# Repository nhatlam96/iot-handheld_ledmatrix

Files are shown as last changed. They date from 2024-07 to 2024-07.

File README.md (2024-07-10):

# Electronica Emporium

- N = Luong, Nhat-Lam
- P = Sandler, Paul
- NP = Both

## Individual and group work packages

- server:
  - N: .env (deleted secret), Dockerfile, mosquitto.conf, mqtt_tictactoe.py
  - P: mqtt_laby.py
- client:
  - N: .env (deleted secret), tictactoe.py
  - P: labyrinth.py, menu.py, common_functions.py
  - NP: mqtt_client.py, vibrator.py, gyroscope_handler.py

## Project timeline

- **Project planning**
  - [x] (NP) Architecture, Project plan, general and individual work packages, hardware research and orders
- **Project implementation**
  - Hardware
    - [x] Setup and testing
      - [x] (N) Connect Buttons and test
      - [x] (N) Research docker and pi connection (MQTT protocol)
      - [x] (N) Research Docker with ChatGPT-3.5 Turbo API
      - [x] (P) Connect LED and test
      - [x] (P) Connect LED to Power Supply and test
      - [x] (P) Connect LED Controller board and test
      - [x] (P) Connect Gyroscope and test
      - [x] (N) Connect Vibration motor and test
    - [x] (NP + DesignLab) Design and creation of the case
    - [x] (NP) Setup VM & Connect Gaming Board
  - Coding
    - [x] (P) Implement input logic (Detect Sensor inputs, process inputs)
    - [x] (P) Implement consistent sensor data transfer to VM
    - [x] (N) Implement output logic (Display the game selection, feedback for input on dispaly)
    - [x] (N) Implement AI API functionality and connection
    - [x] (N) Implement TicTacToe
    - [x] (P) Gyroscope inputs for tictactoe & reset state after each input
    - [x] (P) Implement Labyrinth Game
    - [x] (P) Implement game selection logic (Selection between multiple games, use processed inputs)
    - [x] (NP) Test output/response from input server
    - [x] (NP) Connect input/response server/service with openapi server/service
    - [x] (NP) Testing, bug fixing, quality improvments
- **Project Documentation and Presentation**
  - [x] (NP) Repo Cleanup
  - [x] (NP) Documentation
  - [x] (NP) Presentation

## Hardware

### Rented

| Type | Name | Quantity |
|---|---|---|
| Gateway & Connector | RaspberryPi 4 Model B | 1 |
| Other | RaspberryPi 15 Watt Power Supply | 1 |
| Other | SD Card | 1 |
| Application | LED-Matrix-Panel 64x64 | 1 |
| Sensor | Buttons (Accept, Decline) | 2 |
| Other | Power Supply 50 Watt | 1 |
| Sensor | Gyroscope 3-Axis | 1 |
| Actuator | Vibration Motor | 1 |

### To be returned (unused)

| Type | Name | Quantity |
|---|---|---|
| Sensor | Gyroscope 3-Axis | 1 |
| Other | Shield für RGB-LED-Matrix | 1 |

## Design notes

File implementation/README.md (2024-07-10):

# File structure of the implementation

## Hardware documentation

- In the *docs/hardware* directory, you will find:
  - Setup instructions for the hardware
  - Which pins are used by which hardware
  - Autodesk Fusion files for the case
- All used hardware is found in the README.md in the base dir

## Software documentation

- In the *docs/software* directory, you will find
  - Setup instructions for the needed packages and modules
  - Setup instructions for the PI including
    - Enabling I2C
    - Setting up WLAN
  - How to create a service for running python scripts automaticly
  - How to run the pygame scripts (parameters)
  - How to setup and run the MQTT server

## Case files

- In the *case* directory, you will find the Autodesk Fusion files for the case
- With the following link, you can access the case in the browser: [Case](http://a360.co/3QWGV2a)

## Client files

- In the *client* directory, you will find the client code that are run by the raspberry pi

## Server files

- In the *server* directory, you will find the server code that are run by the VM and docker
- the adress of the server is: `electronicaemporium@iot.it.hs-worms.de`
  - (check implementation/docs/software/setup_&_start_mqtt_docker.md for more information)

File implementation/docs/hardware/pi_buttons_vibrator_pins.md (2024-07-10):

# Sensor pins: Buttons and Vibrator

- Vibrator: GPIO 5 + GND PIN 6 (maybe, please check again)
- Red button: GPIO 16 + GND PIN 34
- Blue button: GPIO 26 + GND PIN 39

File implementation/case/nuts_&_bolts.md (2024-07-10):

# Nuts and bolts of the case

The case requires a few nuts and bolts to be put together. Here is the list:

- 4x of https://www.schraubenhandel24.de/schrauben/gewindeschrauben/gewindefurchende/din-7500/din-7500-gewindefurchende-schrauben-z-form-c-stahl-verzinkt/din7500-gewindefurc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
- 8x of https://www.schraubenhandel24.de/schrauben/gewindeschrauben/linsenkopfschrauben/din-7985/din-7985-linsenkopfschrauben-h-edelstahl-a2/din-7985-linsenkopfschrauben-ede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
- 5x of https://www.schraubenhandel24.de/schrauben/gewindeschrauben/gewindefurchende/din-7500/din-7500-gewindefurchende-schrauben-z-form-c-stahl-verzinkt/din7500-gewindefurc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

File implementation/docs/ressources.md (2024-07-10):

# Resources

## Hardware

- [RaspberryPI GPIO Manual](https://www.raspberrypi.com/documentation/computers/raspberry-pi.html)
- [LED-Matrix Datasheet](https://joy-it.net/files/files/Produkte/LED-Matrix01/LED-Matrix01_Datasheet_2022-07-25.pdf)
- [LED-Matrix Manual](https://joy-it.net/files/files/Produkte/RB-MatrixCtrl/RB-MatrixCtrl_Manual_2021-08-05.pdf)
- [LED-Matrix-Controllboard Datasheet](https://cdn-reichelt.de/documents/datenblatt/A300/DATASHEETRB-MATRIXCTRL.pdf)
- [LED-Matrix-Controllboard Manual](https://cdn-reichelt.de/documents/datenblatt/A300/RB-MATRIXCTRL-ANLEITUNG.pdf)
- [Gyroscope Datasheet](https://www.berrybase.de/Pixelpdfdata/Articlepdf/id/4639/onumber/GY-86)
- [Vibration Motor](https://www.amazon.de/HALJIA-Vibrating-Vibration-Kompatibel-Arduino/dp/B07QL8CMH7)

## Software

- Python libraries
  - Gyroscope: [smbus2](https://pypi.org/project/smbus2/)
  - LED-matrix: [RGBMatrixEmulator](https://pypi.org/project/RGBMatrixEmulator/) / [rpi-rgb-led-matrix](https://github.com/hzeller/rpi-rgb-led-matrix)
  - Vibration motor & Buttons: [Rpi.GPIO](https://pypi.org/project/RPi.GPIO/)
  - Communication: [paho-mqtt](https://pypi.org/project/paho-mqtt/)
- OS: [Raspberry Pi OS (64 bit) via installer](https://www.raspberrypi.com/software/)

## Tutorials

- [MQTT Setup on PI/Docker](https://www.schaerens.ch/raspi-setting-up-mosquitto-mqtt-broker-on-raspberry-pi-docker/)
- [Connect sensors in gernal to PI](https://chipwired.com/connect-sensors-raspberry-pi/)
- [Connect vibration motor to PI](https://peppe8o.com/vibration-module-raspberry-pi/)
- [Connect gyroscope to PI](https://peppe8o.com/using-gyroscope-and-accelerometer-with-mpu6050-raspberry-pi-pico-and-micropython/)
- [Connect buttons to PI](https://raspberrypihq.com/use-a-push-button-with-raspberry-pi-gpio/)
- [Connect LED-Panel with PI](https://howchoo.com/pi/raspberry-pi-led-matrix-panel/)

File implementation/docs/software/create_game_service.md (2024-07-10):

# Service erstellen für pigame

1. `sudo nano /etc/systemd/system/pigame.service`
2. Insert and save:
    ```
    [Unit]
    Description=Run PiGame on boot
    After=network.target

    [Service]
    ExecStart=/bin/bash -c 'source /home/pi/venv/bin/activate && exec python3 /home/pi/rpi-rgb-led-matrix/bindings/python/samples/menu.py --led-no-hardware-pulse=true --led-rows=64 --led-cols=64 --led-slowdown-gpio=5'
    WorkingDirectory=/home/pi
    User=pi
    Group=pi
    Restart=always

    [Install]
    WantedBy=multi-user.target
    ```
3. `sudo systemctl daemon-reload`
4. `sudo systemctl enable pigame.service`
5. `sudo systemctl start pigame.service`

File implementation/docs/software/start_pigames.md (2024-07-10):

# First time pigame setup

1. `ssh pi@ip` pw: `wasd1234`
2. Copy files from `/raspverrypi/*` to `pi@ip:/home/pi/`
3. `sudo apt update && sudo apt install python3-pip mosquitto mosquitto-clients -y`
4. `pip install -r requirements.txt`

# Run pigames

1. `source ~/venv/bin/activate && python3 ~/rpi-rgb-led-matrix/bindings/python/samples/menu.py --led-no-hardware-pulse=true --led-rows=64 --led-cols=64 --led-slowdown-gpio=5`

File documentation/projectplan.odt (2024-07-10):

University of Applied Sciences Worms

Degree: Applied Computer Science (B.Sc.)

Course: 507 IOT

IOT AI Gaming: Electronica Emporium Gamingstation

Electronica Emporium

Paul Sandler (inf3675), Nhat-Lam Luong's (inf3381)

SoSe24 with Prof. Dr. Volker Schwarzer

# Project description

- Objective: Develop a versatile hardware board capable of supporting multiple games, including TicTacToe, Connect Four, and potentially others.
- Hardware Components:
  - Utilization of an LED display for visual output.
  - Integration of input mechanisms comprising buttons and a gyroscope for user interaction.
- Backend Logic:
  - Implementation of the backend logic on a Virtual Machine.
  - AI Integration:
    - Integration of an AI, specifically a Language Model, to serve as an opponent for users.
    - Communication with the AI only happens once the backend requires input.
- Reusability:
  - Designed for potential expansion to accommodate additional games, enhancing the board's versatility.
- Overall Aim:
  - To create a robust and adaptable hardware platform that provides engaging gaming experiences across various titles while leveraging modern technologies like AI.

# Project plan

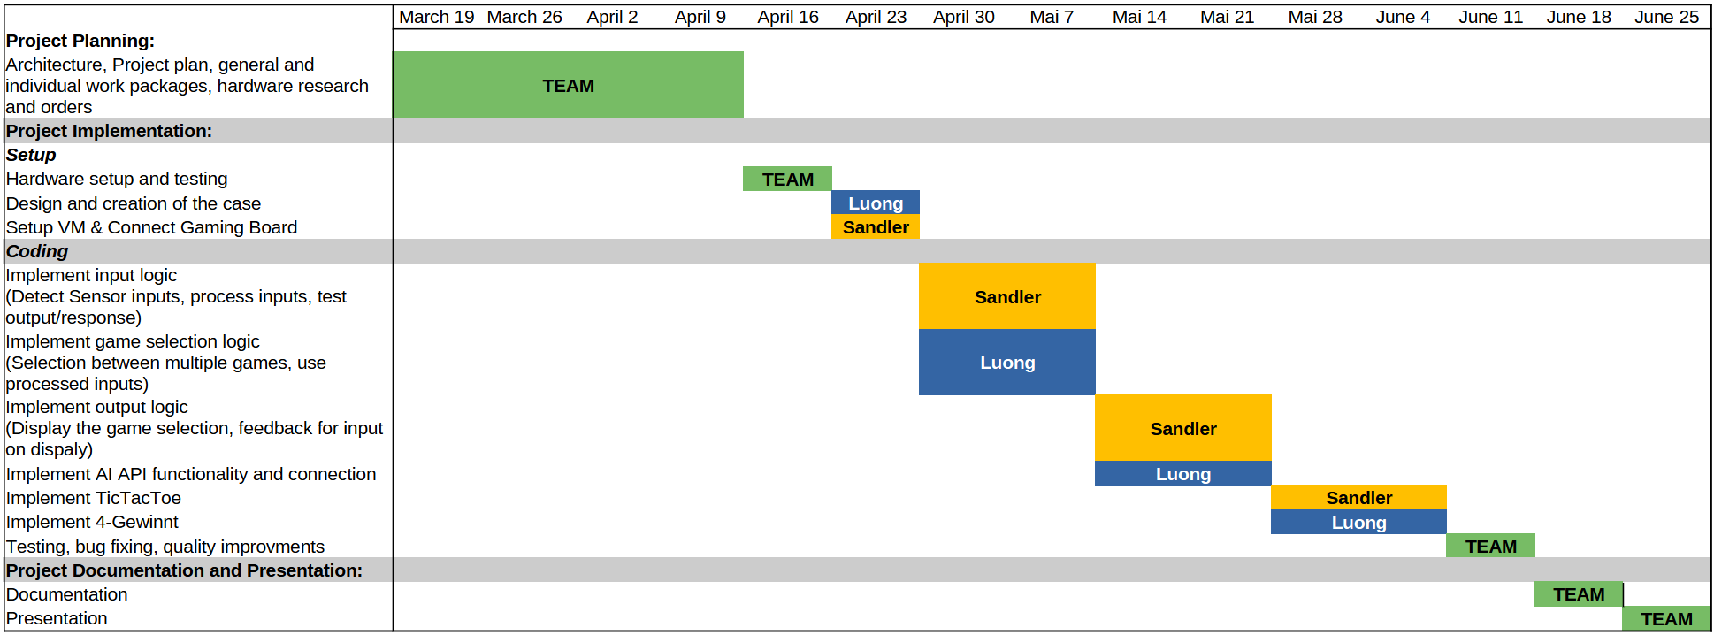
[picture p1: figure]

# Architecture

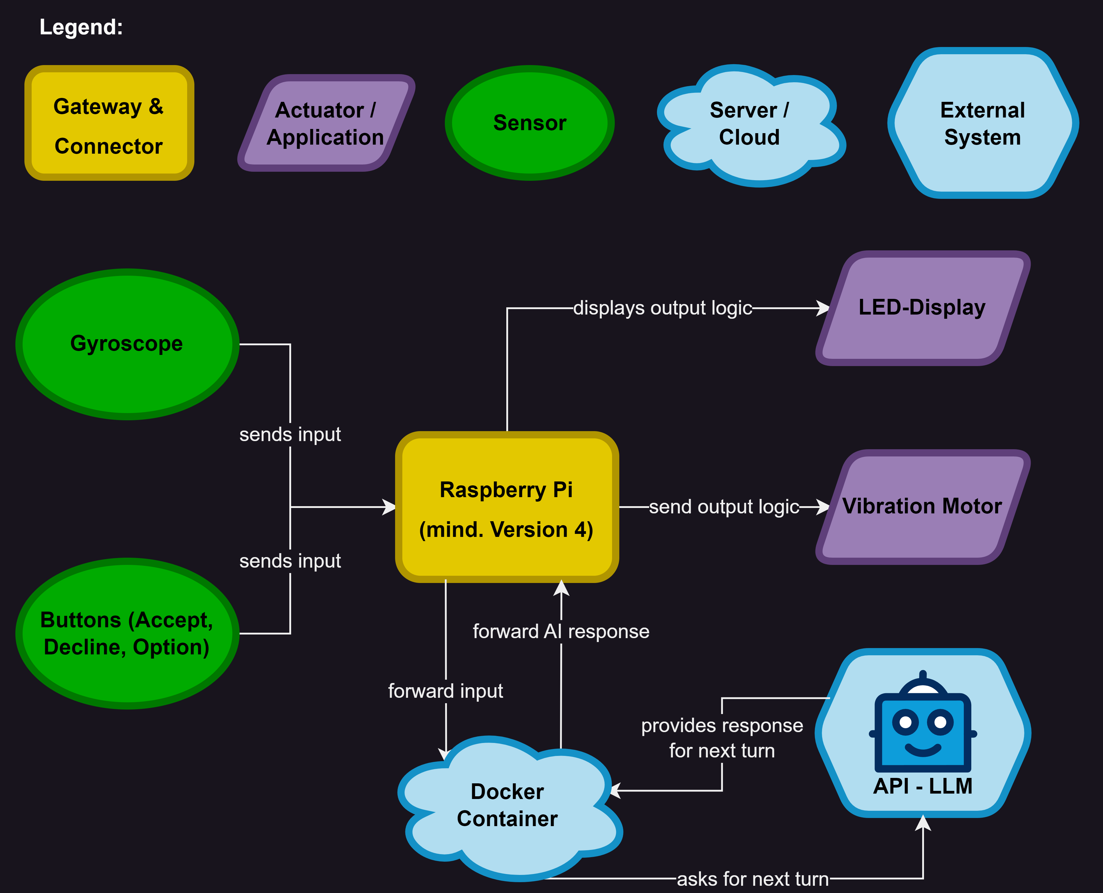
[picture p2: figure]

# Requirements

## Hardware

Type | Name | Quantity | Cost | Link
Gateway & Connector | RaspberryPi (min. V4) | 1 | 59,51€ OR 0,00€ | amazon.de (https://www.amazon.de/Raspberry-Pi-4595-Modell-GB/dp/B09TTNF8BT?__mk_de_DE=ÅMÅŽÕÑ) OR In Stock
Other | Raspberry PI Power Supply | 1 | 9,64€ OR 0,00€ | amazon.de (https://www.amazon.de/Raspberry-Pi-offizielles-Netzteil-Model/dp/B07TMPC9FG?__mk_de_DE=ÅMÅŽÕÑ) OR In Stock
Sensor | Buttons (Accept, Decline, Options) | 3 | 3,99€ OR 0,00€ | amazon.de (https://www.amazon.de/AZDelivery-KY-004-Schalter-Schlüsselschalter-Arduino/dp/B07DPSMRJ6?__mk_de_DE=ÅMÅŽÕÑ) OR In Stock
Sensor | Gyroscope | 1 | 4,99€ | amazon.de (https://www.amazon.de/ARCELI-Beschleunigungsmesser-Gyroskop-Beschleunigungssensor-Datenausgang/dp/B07BVXN2GP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ÅMÅŽÕÑ)
Application | LED-Matrix-Panel | 1 | 0,00€ | In Stock
Actuator | Vibration Motor | 1 | 7,99€ | amazon.de (https://www.amazon.de/HALJIA-Vibrating-Vibration-Kompatibel-Arduino/dp/B07QL8CMH7?__mk_de_DE=ÅMÅŽÕÑ)

## Software

- OpenAI's GPT-3 API & API Access/Key
- Python Libraries
  - Gyroscope: smbus
  - LED-matrix: rpi-rgb-led-matrix
  - Vibration motor & Buttons: Rpi.GPIO
  - Communication: paho-mqtt
- Protocol (RaspberryPI to Cloud): MQTT (via paho-mqtt)

## Tools

- Soldering tools/station
- 3D-Design software
- 3D-Printer for case

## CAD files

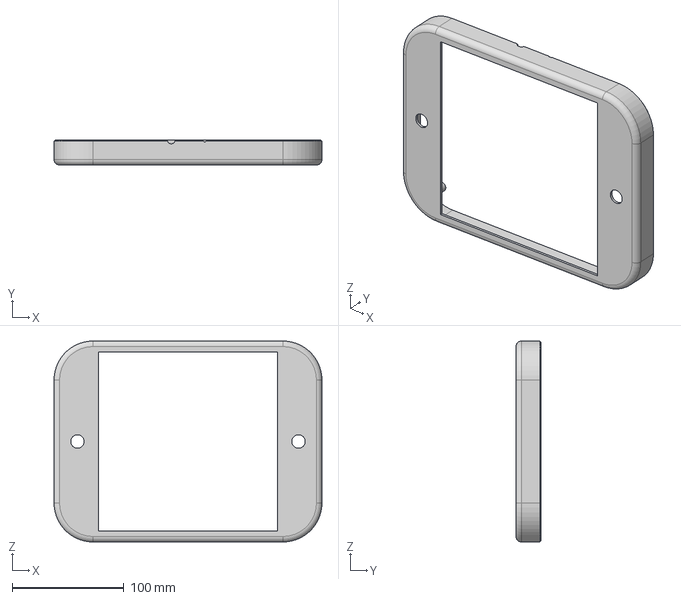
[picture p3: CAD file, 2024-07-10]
implementation/case/case v7 - body1.step
240.0 x 22.5 x 180.0 mm

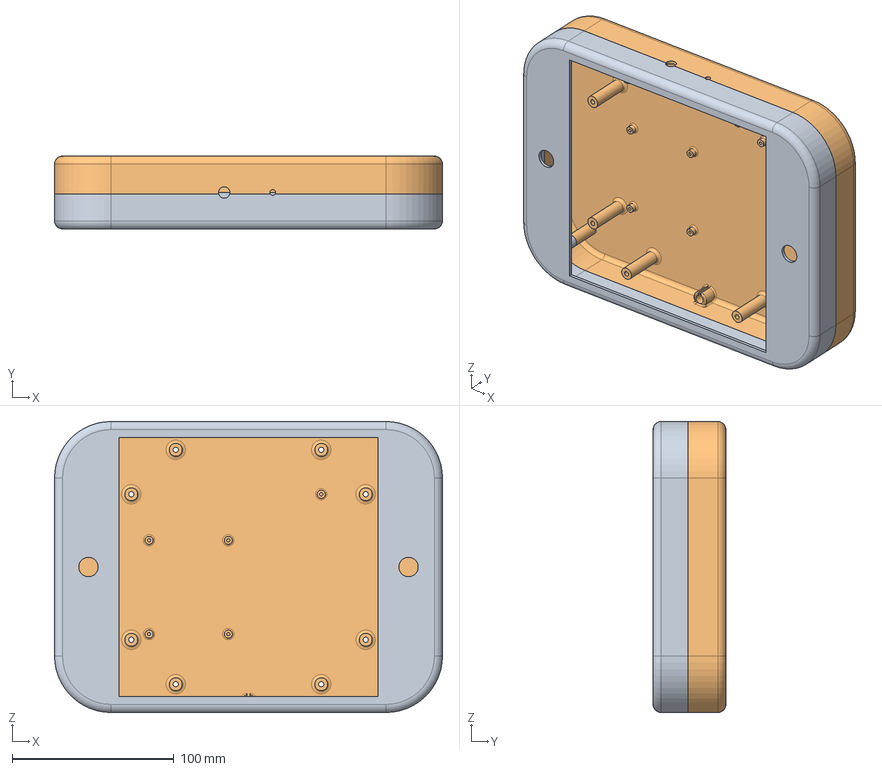
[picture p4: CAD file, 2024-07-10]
implementation/case/case v7.step
240.0 x 45.0 x 180.0 mm

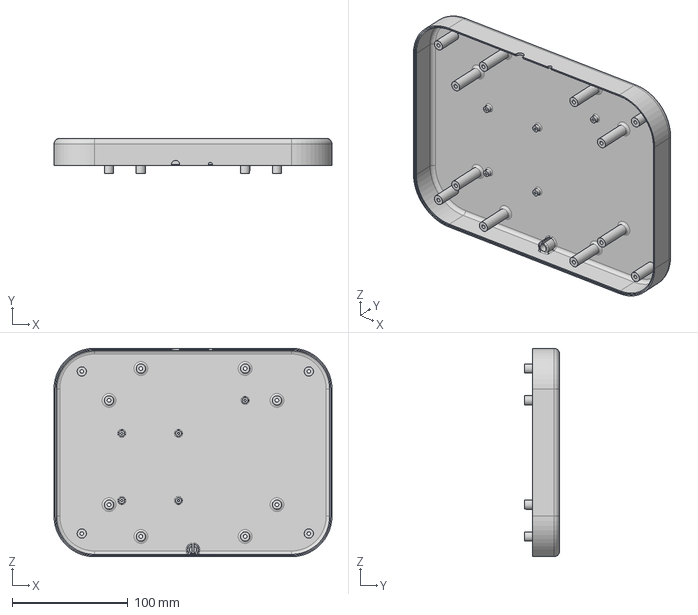
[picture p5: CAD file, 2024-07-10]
implementation/case/case v7 - body2.step
240.0 x 30.5 x 180.0 mm

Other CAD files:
implementation/case/case v7 - body1.stl
implementation/case/case v7 - body2.stl
implementation/case/case v7.stl

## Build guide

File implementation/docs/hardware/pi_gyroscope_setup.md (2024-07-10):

# Gyroscope Setup

## Remarks

- The LED on the gyroscope should light up, indicating it is correctly connected.

## Specifications

- **Chipsets:**
  - MS5611 (Barometer)
  - HMC5883L (3-Axis Magnetometer)
  - MPU6050 (3-Axis Gyroscope & Triaxial Accelerometer)
- **Communication:** I2C Interface
- **Power Supply:** 3-5V

## RaspberryPi software config

- Enable I2C
  - Run `sudo raspi-config`
  - Interface Options -> I2C -> Enable
  - Follow the tutorial (Reference 3), but use Python 3 and install GPIO with `sudo apt install python3-rpi.gpio pigpio python3-pigpio`.

## Connecting the hardware

- Connect VCC_IN to 3V (Pin 1)
- Connect GND to GND (Pin 9)
- Connect SCL to GPIO 3 (SCL, Pin 5)
- Connect SDA to GPIO 2 (SDA, Pin 3)
- Note: Pins used: 1 (3V), 5 (SCL), 9 (GND), 3 (SDA)

## Testing

- Test if the gyroscope is correctly connected with `sudo i2cdetect -y 1`

## References and Ressources

1. [Gyroscope Datasheet](https://www.berrybase.de/Pixelpdfdata/Articlepdf/id/4639/onumber/GY-86)
2. [Gyroscope python lib smbus2](https://pypi.org/project/smbus2/)
3. [Gyroscope Tutorial for RaspberryPi](https://www.raspberrypistarterkits.com/guide/raspberry-pi-accelerometer-gyroscope/)
4. [How to use gyrosope in python](https://www.electronicwings.com/raspberry-pi/mpu6050-accelerometergyroscope-interfacing-with-raspberry-pi)

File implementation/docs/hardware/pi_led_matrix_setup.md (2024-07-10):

# LED Matrix Setup

## Specifications

- **Supply Voltage:** 5V / approximately 4A per LED matrix
- **Maximum Consumption:** 40W
- **Resolution:** 64 x 64
- **Number of LEDs:** 4096

## Connecting the Hardware

1. **Connect LED Power Cable:**
   - Connect the power cable to the LED matrix.
   - Connect the power cable to the power supply.
2. **Connect HUB75 Connector:**
   - Use a ribbon cable to connect the HUB75 connector to the IN port on the matrix.
3. **Connect Pins to Raspberry Pi:**
   - Refer to Reference 2 for GPIO and IN diagram.
   - All connector cables (16) are needed except N.
   - LE is E, LA is A, LB is B, LC is C, LD is D.

## Setting up & Testing the Software

1. **Disable Audio Module:**
   - `sudo nano /boot/firmware/config.txt`
   - Change `dtparam=audio=on` to `dtparam=audio=off`
   - Reboot and run `lsmod` to check for `snd_bcm2835`. If present, run:

    ```bash
    cat <<EOF | sudo tee /etc/modprobe.d/blacklist-rgb-matrix.conf
    blacklist snd_bcm2835
    EOF

    sudo update-initramfs -u
    ```

   - Reboot.
2. **Install Matrix Packages:** Refer to Reference 2. Only Matrix 1 is used.
3. **Install Python Packages:** Refer to Reference 2.

4. **Build and Install Python Packages:**

  ```bash
  cd ~/rpi-rgb-led-matrix
  make build-python
  sudo make install-python
  sudo setcap 'cap_sys_nice=eip' /usr/bin/python3.11
  ```

5. **Activate Virtual Environment:**
  `source venv/bin/activate`

6. **Test Commands:**

```bash
sudo ~/rpi-rgb-led-matrix/examples-api-use/demo -D 0 --led-rows=64 --led-cols=64 --led-slowdown-gpio=4
sudo ~/rpi-rgb-led-matrix/examples-api-use/scrolling-text-example --led-rows=64 --led-cols=64 --led-slowdown-gpio=4 -f ~/LED_props/cherry-10-b.bdf Hallo Welt!
sudo ~/rpi-rgb-led-matrix/examples-api-use/text-example -f ~/LED_props/cherry-10-b.bdf --led-rows=64 --led-cols=64
python3 ~/rpi-rgb-led-matrix/bindings/python/samples/simple-square.py --led-no-hardware-pulse=true --led-cols=64 --led-rows=64 --led-slowdown-gpio=4
sudo python3 ~/rpi-rgb-led-matrix/bindings/python/samples/image-viewer.py ~/LED_props/Wikipedia_Logo.png --led-cols=64 --led-rows=64 --led-slowdown-gpio=4
python3 ~/rpi-rgb-led-matrix/bindings/python/samples/main-gyro.py --led-no-hardware-pulse=true --led-rows=64 --led-cols=64 --led-slowdown-gpio=5
```

## References and Ressources

1. [LED-Matrix Datasheet](https://joy-it.net/files/files/Produkte/LED-Matrix01/LED-Matrix01_Datasheet_2022-07-25.pdf)
2. [LED-Matrix Manual](https://joy-it.net/files/files/Produkte/RB-MatrixCtrl/RB-MatrixCtrl_Manual_2021-08-05.pdf)
3. [LED-Matrix-Controllboard Datasheet](https://cdn-reichelt.de/documents/datenblatt/A300/DATASHEETRB-MATRIXCTRL.pdf)
4. [LED-Matrix-Controllboard Manual](https://cdn-reichelt.de/documents/datenblatt/A300/RB-MATRIXCTRL-ANLEITUNG.pdf)
5. [RGBMatrixEmulator](https://pypi.org/project/RGBMatrixEmulator/) / [rpi-rgb-led-matrix](https://github.com/hzeller/rpi-rgb-led-matrix)
6. [Connect LED-Panel with PI](https://howchoo.com/pi/raspberry-pi-led-matrix-panel/)

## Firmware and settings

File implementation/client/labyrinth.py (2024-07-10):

import RPi.GPIO as GPIO
from time import sleep
from random import shuffle, random
from samplebase import SampleBase
from rgbmatrix import graphics
from vibrator import setVibrator
from gyroscope_handler import get_tilt_direction
from common_functions import (
    clear_display,
    setup_gpio,
    draw_centered_text,
    load_font,
    GameExit,
    update_button_states
)
from mqtt_client import MQTTClient

# MQTT Broker details
TOPIC_QUERY = "labyrinth/query"
TOPIC_RESPONSE = "labyrinth/response"


class LabyrinthGame(SampleBase):
    """
    Main class for the labyrinth game.
    """

    def __init__(self, *args, **kwargs):
        super(LabyrinthGame, self).__init__(*args, **kwargs)

        # Initialize MQTT client
        self.mqtt_client = MQTTClient(TOPIC_QUERY, TOPIC_RESPONSE)

        # LED panel size in pixels
        self.led_pixel_x = 64
        self.led_pixel_y = 64

        # Cell size in pixels
        self.game_cell_size = 4

        # Game dimensions in cells (16x16 cells)
        self.game_dimension_x = int(self.led_pixel_x / self.game_cell_size)
        self.game_dimension_y = int(self.led_pixel_y / self.game_cell_size)

        # Game-specific variables
        # Exit postion is bottom-left
        self.exit_position = (0, self.game_dimension_y - 1)
        # Start position is top-right
        self.start_position = (self.game_dimension_x - 1, 0)
        # Player's starting position
        self.current_position = self.start_position
        self.game_over = False
        self.game_won = False

        # Request maze from server via MQTT
        self.grid, self.deadlyWalls = self.request_maze_from_server(self.game_dimension_x,
                                                                    self.game_dimension_y,
                                                                    self.exit_position,
                                                                    self.start_position
                                                                    )

        # GPIO setup
        setup_gpio(self)

        # Font setup
        self.font = load_font(self)
        # Yellow text color
        self.text_color = graphics.Color(200, 200, 0)
        # Black for paths
        self.bg_color = graphics.Color(0, 0, 0)
        # White for walls
        self.bg_alt_color = graphics.Color(255, 255, 255)
        # Orange for deadly walls
        self.bg_deadly_wall_color = graphics.Color(187, 69, 111)
        # Green for the player
        self.player_colour = graphics.Color(0, 255, 0)
        # Red for the exit
        self.exit_positon_colour = graphics.Color(255, 0, 0)

        # Button states setup
        self.blue_button = None
        self.red_button = None
        update_button_states(self)

    def request_maze_from_server(self, width, height, exit_position, start_position):
        '''
        Request maze generation from the server via MQTT.

        Args:
            self: The instance who calls the function.
            width (int): Width of maze in cells.
            height (int): Height of maze in cells.

        Returns:
            list: Generated maze with walls (1) and paths (0).
        '''

        request = {'width': width, 'height': height,
                   'exit_position': exit_position,
                   'start_position': start_position}
        self.mqtt_client.publish(TOPIC_QUERY, request)
        response = self.mqtt_client.get_response()
        fixedWalls = [tuple(sublist) for sublist in response['deadlyWalls']]
        return response['maze'], fixedWalls

    def draw_grid(self, canvas):
        '''
        Draws the maze grid, player and exit position of the canvas.

        Args:
            self: The instance who calls the function.
            canvas: Drawing suface.

        Returns:
            list: Generated maze with walls (1) and paths (0).
        '''

        # Iterates over each cell in the grid
        for y in range(len(self.grid)):
            for x in range(len(self.grid[0])):
                # If the current cell is in deadly walls
                if (x, y) in self.deadlyWalls:
                    # Set it's colour as deadly wall
                    color = self.bg_deadly_wall_color
                # If the current cell is a wall
                elif self.grid[y][x] == 1:
                    # Set it's colour as normal wall
                    color = self.bg_alt_color
                # Otherwise, set it's colour as a path
                else:
                    color = self.bg_color

                # Draw each cell as the appropriate size (game_cell_size)
                # dy and dx are offsets within each cell
                for dy in range(self.game_cell_size):
                    for dx in range(self.game_cell_size):
                        # Sets the Pixel at the current positon
                        canvas.SetPixel(x * self.game_cell_size + dx,
                                        y * self.game_cell_size + dy,
                                        color.red, color.green, color.blue)

        # Get current position of the player
        cx, cy = self.current_position

        # Draw the current position of the player
        # dy and dx are offsets within the player cell
        for dy in range(self.game_cell_size):
            for dx in range(self.game_cell_size):
                # Sets the Pixel at the current position
                canvas.SetPixel(cx * self.game_cell_size + dx,
                                cy * self.game_cell_size + dy,
                                self.player_colour.red,
                                self.player_colour.green,
                                self.player_colour.blue)

        # Get position of the exit
        ex, ey = self.exit_position

        # Draw the exit position
        # dy and dx are offsets within the exit cell
        for dy in range(self.game_cell_size):
            for dx in range(self.game_cell_size):
                # Sets the Pixel at the current position
                canvas.SetPixel(ex * self.game_cell_size + dx,
                                ey * self.game_cell_size + dy,
                                self.exit_positon_colour.red,
                                self.exit_positon_colour.green,
                                self.exit_positon_colour.blue)

    def update_display(self, canvas, message=None):
        '''
        Updates the display on the canvas.
        If a message is provided, display it centered.

        Args:
            self: The instance who calls the function.
            canvas: Drawing surface.
            message (str): Message to be displayed (optional).
        '''

        # Draws current state of the maze on the canvas
        self.draw_grid(canvas)
        # If message is provided
        if message:
            canvas.Clear()
            # Draw the message as centered text
            draw_centered_text(self, canvas, self.font, 20, self.text_color,
                               message)
        # Update display with newly drawn canvas
        self.matrix.SwapOnVSync(canvas)

    def move_player(self, canvas, direction):
        '''
        Move the player in specified direction, if the move is valid.
        Updates the position and display on the canvas.

        Args:
            self: The instance who calls the function.
            canvas: Drawing surface.
            direction (str): The direction in which the player wants to move.
        '''

        # Get's current player positon
        x, y = self.current_position
        # Initializes copy of current player positoin
        new_x, new_y = x, y

        # If moving up is within bounds
        if direction == 'UP' and y > 0:
            # If target cell is deadly wall
            if (x, y - 1) in self.deadlyWalls:
                self.game_over = True
            # If target cell is wall or exit position
            elif self.grid[y - 1][x] == 0 or (x + 1, y) == self.exit_position:
                new_y -= 1
        # If moving down is within bounds
        elif direction == 'DOWN' and y < len(self.grid) - 1:
            # If target cell is deadly wall
            if (x, y + 1) in self.deadlyWalls:
                self.game_over = True
            # If target cell is a wall or exit position
            elif self.grid[y + 1][x] == 0 or (x, y + 1) == self.exit_position:
                new_y += 1
        # If moving left is within bounds
        elif direction == 'LEFT' and x > 0:
            # If target cell is deadly wall
            if (x - 1, y) in self.deadlyWalls:
                self.game_over = True
            # If target cell is a wall or exit position
            elif self.grid[y][x - 1] == 0 or (x + 1, y) == self.exit_position:
                new_x -= 1
        # If moving right is within bounds
        elif direction == 'RIGHT' and x < len(self.grid[0]) - 1:
            # If target cell is deadly wall
            if (x + 1, y) in self.deadlyWalls:
                self.game_over = True
            # If target cell is a wall or exit position
            if self.grid[y][x + 1] == 0 or (x + 1, y) == self.exit_position:
                new_x += 1

        # If game is not over
        if not self.game_over:
            # Set new postion to current
            self.current_position = (new_x, new_y)
            self.update_display(canvas)

    def run(self):
        '''
        Main method of the game.
        Handels the game flow, including initializing the game,
        updating the display, handling user input and
        managing the game state (win, loss, restart).

        Args:
            self: The instance who calls the function.
        '''

        # Initial setup of game loop
        setup_gpio(self)
        # Create new canvas
        canvas = self.matrix.CreateFrameCanvas()
        # Update display with initial state of game
        self.update_display(canvas)

        try:
            game_over_message_shown = False

            while True:
                update_button_states(self)

                if self.game_won:
                    if not game_over_message_shown:
                        self.update_display(canvas, "You won!")
                        game_over_message_shown = True
                        setVibrator(1.2)
                        sleep(1)
                    if game_over_message_shown:
                        self.exit_cleanly(canvas)
                    sleep(0.3)
                    continue

                if self.game_over:
                    game_over_message_shown = self.restart_game(canvas,
                                                                "Gameover!")
                    sleep(0.3)
                    continue

                # If both buttons are pressed
                if (self.blue_button == GPIO.LOW and
                   self.red_button == GPIO.LOW):
                    game_over_message_shown = self.restart_game(canvas,
                                                                "Restarting!")
                    sleep(0.3)

                # Get tilt direction and magnitue of the game board
                tilt_direction, tilt_magnitude = get_tilt_direction()

                # If tilt direction is not none
                if tilt_direction != 'NONE':
                    # Constrain the speed_factor min 0.1 and max 1
                    speed_factor = max(0.1, min(1, tilt_magnitude))
                    # Calculate the sleep_time via speed factor
                    sleep_time = 0.1 * (1 - speed_factor)

                    self.move_player(canvas, tilt_direction)
                    if self.current_position == self.exit_position:
                        self.game_won = True
                        game_over_message_shown = False
                        sleep(1)

                    # Sleep based on sleep_facor
                    sleep(sleep_time)

                # If blue button, but not red button is pressed
                if (self.blue_button == GPIO.LOW and
                   self.red_button != GPIO.LOW):
                    sleep(0.3)

                # If red button, but not blue button is pressed
                if (self.red_button == GPIO.LOW and
                   self.blue_button != GPIO.LOW):
                    setVibrator(0.1)
                    self.exit_cleanly(canvas)

                sleep(0.1)

        except KeyboardInterrupt:
            print("\nProgram exited by interrupt.")

        finally:
            GPIO.cleanup()

    def exit_cleanly(self, canvas):
        '''
        Exits the game cleanly, displays a exit message,
        cleans up the display and raises a exit exception.

        Args:
            self: The instance who calls the function.
            canvas: Drawing surface.

        Raises:
            GameExit: Exception raised to cleanly exit the game.
        '''
        self.update_display(canvas, "Exiting!")
        sleep(1)
        clear_display(self, canvas)
        GPIO.cleanup()
        sleep(0.3)
        raise GameExit

    def restart_game(self, canvas, message):
        '''
        Restarts the game, displays a restart message,
        cleans up the display and reinitializes the game.

        Args:
            self: The instance who calls the function.
            canvas: Drawing surface.
            message (str): Message to be displayed.

        Return:
            bool: The status of the game_over_message.
        '''
        self.update_display(canvas, message)
        setVibrator(1.2)
        sleep(1)
        clear_display(self, canvas)
        self.__init__()
        self.update_display(canvas)
        game_over_message_shown = False
        return game_over_message_shown


if __name__ == "__main__":
    labyrinth_game = LabyrinthGame()
    if not labyrinth_game.process():
        labyrinth_game.print_help()

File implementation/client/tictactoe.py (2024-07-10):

import RPi.GPIO as GPIO
from time import sleep
from samplebase import SampleBase
from vibrator import setVibrator
from gyroscope_handler import get_tilt_direction
from common_functions import setup_gpio, GameExit, update_button_states
from mqtt_client import MQTTClient
# for some reason it doesn't recognize the load_dotenv function directly
from dotenv import main
# so we have to import it from the main module
main.load_dotenv()

# MQTT Broker details
TOPIC_QUERY = "tictactoe/input"
TOPIC_RESPONSE = "tictactoe/output"


class TicTacToeGame(SampleBase):
    '''
    Main class for the Tic-Tac-Toe game.
    '''

    def __init__(self, *args, **kwargs):
        '''
        Initialize the Tic-Tac-Toe game instance.
        '''
        super(TicTacToeGame, self).__init__(*args, **kwargs)

        # Initialize MQTT client
        self.mqtt_client = MQTTClient(TOPIC_QUERY, TOPIC_RESPONSE)

        # Initialize empty grid and current position at the top-left corner
        self.grid = [[None for _ in range(3)] for _ in range(3)]
        self.current_position = (0, 0)
        self.game_over = False

        # GPIO setup and reset button states
        setup_gpio(self)
        self.blue_button = None
        self.red_button = None
        update_button_states(self)

    def draw_grid(self, canvas):
        '''
        Draw the Tic-Tac-Toe grid on the canvas.
        '''
        width = self.matrix.width
        height = self.matrix.height
        third_width = width // 3
        third_height = height // 3

        # it will iterate twice, so it will draw 2 vert. and 2 hor. lines
        for i in range(1, 3):
            line_x = i * third_width
            line_y = i * third_height
            for j in range(height):  # vertical lines
                canvas.SetPixel(line_x, j, 255, 255, 255)
            for k in range(width):  # horizontal lines
                canvas.SetPixel(k, line_y, 255, 255, 255)

    def draw_x(self, canvas, cx, cy, half_size, color):
        '''
        Draw an 'X' symbol on the canvas.

        Args:
            canvas: The drawing surface on which to draw the 'X' symbol.
            cx: The x-coordinate of the center of the 'X' symbol.
            cy: The y-coordinate of the center of the 'X' symbol.
            half_size: Half the size of the 'X' symbol, determining its length from the center to the ends.
            color: A tuple representing the RGB color values (e.g., (255, 0, 0) for red).
        '''
        for i in range(-half_size, half_size + 1):
            if 0 <= cx + i < self.matrix.width:
                if 0 <= cy + i < self.matrix.height:
                    # diagonal line from bottom-left to top-right
                    canvas.SetPixel(cx + i, cy + i, *color)
                if 0 <= cy - i < self.matrix.height:
                    # diagonal line from top-left to bottom-right
                    canvas.SetPixel(cx + i, cy - i, *color)

    def draw_o(self, canvas, cx, cy, radius, color):
        '''
        Draw an 'O' symbol on the canvas.
        '''
        x = radius
        y = 0
        radius_error = 1 - x

        # Loop to draw the circle using the midpoint circle algorithm
        while x >= y:
            for points in [
                (cx + x, cy + y), (cx - x, cy + y), (cx + x, cy - y),
                (cx - x, cy - y), (cx + y, cy + x), (cx - y, cy + x),
                (cx + y, cy - x), (cx - y, cy - x)
            ]:
                px, py = points
                if (0 <= px < self.matrix.width
                        and 0 <= py < self.matrix.height):
                    canvas.SetPixel(px, py, *color)

            y += 1
            if radius_error < 0:
                radius_error += 2 * y + 1
            else:
                x -= 1
                radius_error += 2 * (y - x + 1)

    def highlight_cell(self, canvas, row, col, color, half_size):
        '''
        Highlight the selected cell with crosshairs or the symbol.
        '''
        width = self.matrix.width
        height = self.matrix.height
        third_width = width // 3
        third_height = height // 3
        cell_width_start = col * third_width
        cell_height_start = row * third_height
        cx = cell_width_start + third_width // 2
        cy = cell_height_start + third_height // 2

        # If the cell is empty, draw crosshairs
        if self.grid[row][col] is None:
            crosshair_color = (100, 100, 100)
            crosshair_length = min(third_width, third_height) // 4

            # Draw horizontal crosshair
            for i in range(cx - crosshair_length, cx + crosshair_length + 1):
                if 0 <= i < width:
                    canvas.SetPixel(i, cy, *crosshair_color)

            # Draw vertical crosshair
            for j in range(cy - crosshair_length, cy + crosshair_length + 1):
                if 0 <= j < height:
                    canvas.SetPixel(cx, j, *crosshair_color)

            # Draw inner square
            inner_square_size = min(third_width, third_height) // 8
            inner_square_color = (100, 100, 100)
            for i in range(cx - inner_square_size, cx + inner_square_size + 1):
                for j in range(cy - inner_square_size,
                               cy + inner_square_size + 1):
                    if 0 <= i < width and 0 <= j < height:
                        if i in (cx - inner_square_size, cx + inner_square_size
                                 ) or j in (cy - inner_square_size,
                                            cy + inner_square_size):
                            canvas.SetPixel(i, j, *inner_square_color)
        # If the cell is not empty, draw the symbol in another color
        else:
            symbol = self.grid[row][col]
            if symbol == "X":
                self.draw_x(canvas, cx, cy, half_size, (255, 0, 255))
            elif symbol == "O":
                self.draw_o(canvas, cx, cy, half_size, (0, 255, 255))

    def highlight_winning_line(self, canvas, winning_line, color1, color2):
        '''
        Highlight the winning line on the canvas.

        Args:
            self: The instance who calls the function.
            canvas: Drawing surface.
            winning_line: List of tuples with coordinates of the winning line.
            color1: RGB color tuple for the start of the gradient.
            color2: RGB color tuple for the end of the gradient.
        '''
        # Print for debugging purposes
        print(f"Highlighting winning line: {winning_line}")

        # Iterate through each cell in the winning line
        for i, (row, col) in enumerate(winning_line):
            # Calculate the x and y- cell center coordinates
            cx = col * (self.matrix.width // 3) + (self.matrix.width // 3) // 2
            cy = row * (self.matrix.height // 3) + (self.matrix.height //
                                                    3) // 2
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
